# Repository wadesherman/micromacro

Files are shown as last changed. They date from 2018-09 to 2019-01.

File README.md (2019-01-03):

# micromacro
An 8 key macro keyboard

## Parts List
* 1x Sparkfun Pro Micro 5v
* 1x Breakaway Headers
* 8x Cherry Key Switches
* 8x Diodes
* 8x Keycaps
* 1x Case

Sparkfun Wishlist: <http://sfe.io/w149906](http://sfe.io/w149906>

## Assembly
1. Collect all your parts
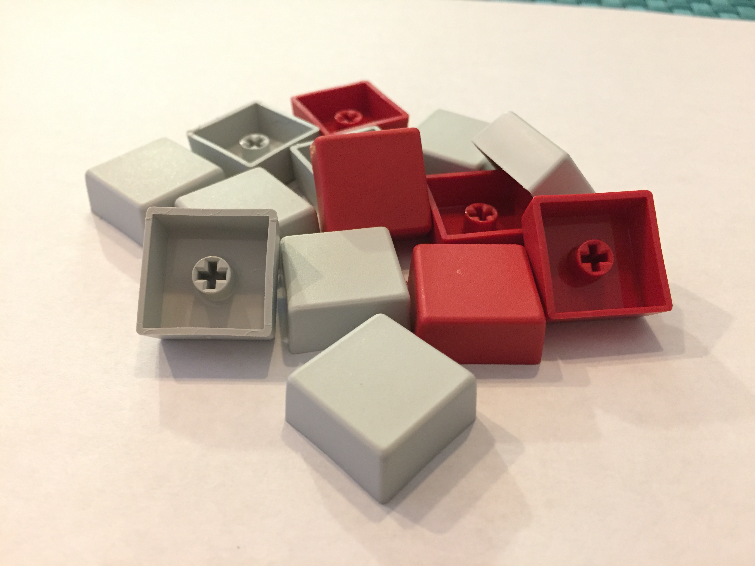
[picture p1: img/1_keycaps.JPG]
  
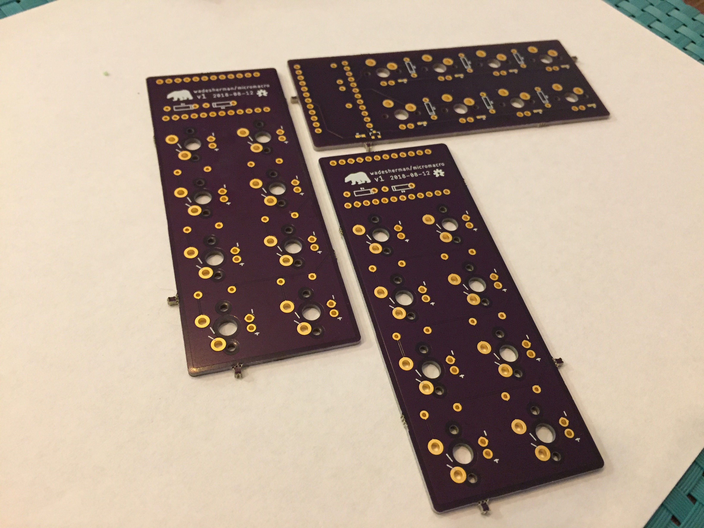
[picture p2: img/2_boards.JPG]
  
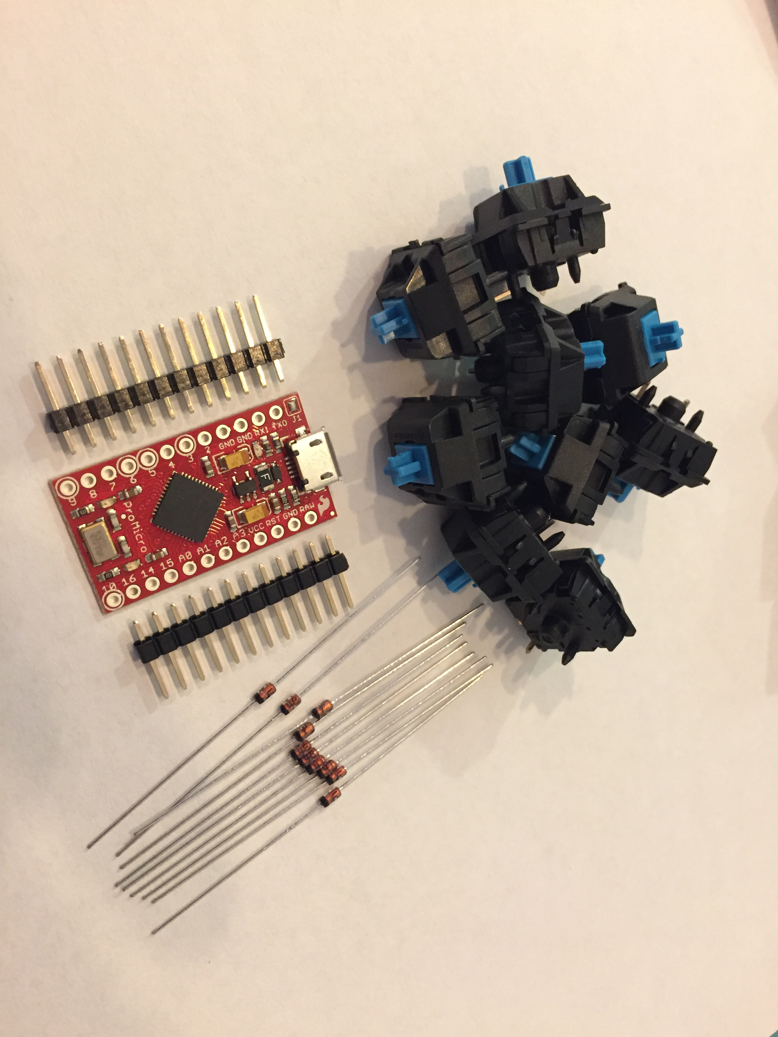
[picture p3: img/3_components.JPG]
  
2. Bend all the diodes - its easier and neater to bend them before
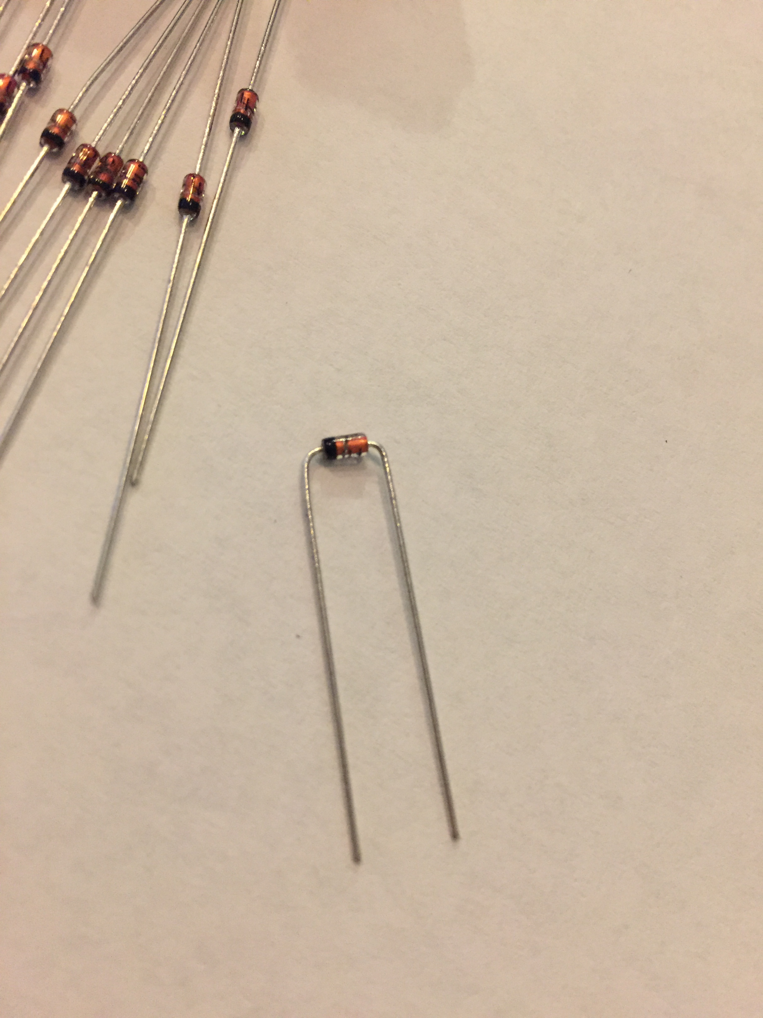
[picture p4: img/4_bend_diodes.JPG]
  
3. Populate the board with all the diodes and then solder them in place - bending the legs out a little will hold the diodes in place until you have a chance to solder them.
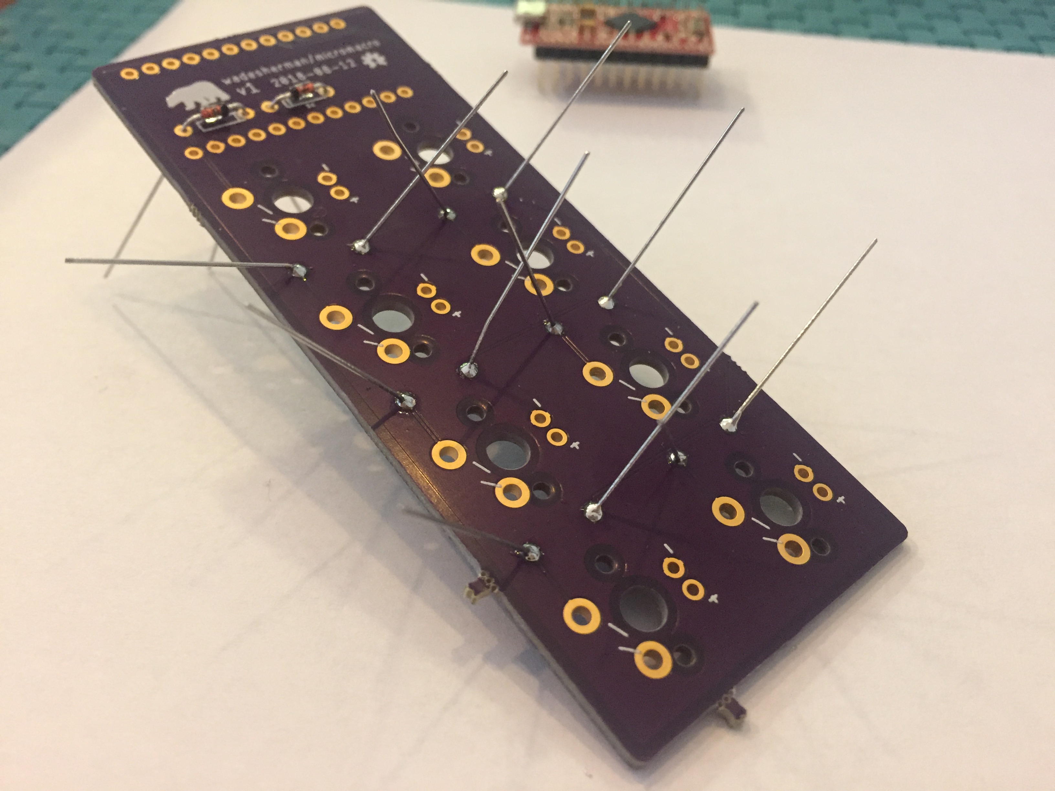
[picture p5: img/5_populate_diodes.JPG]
  
4. Solder the headers to the Pro Micro - it is easiest to just solder one or two pins to hold things together loosely.
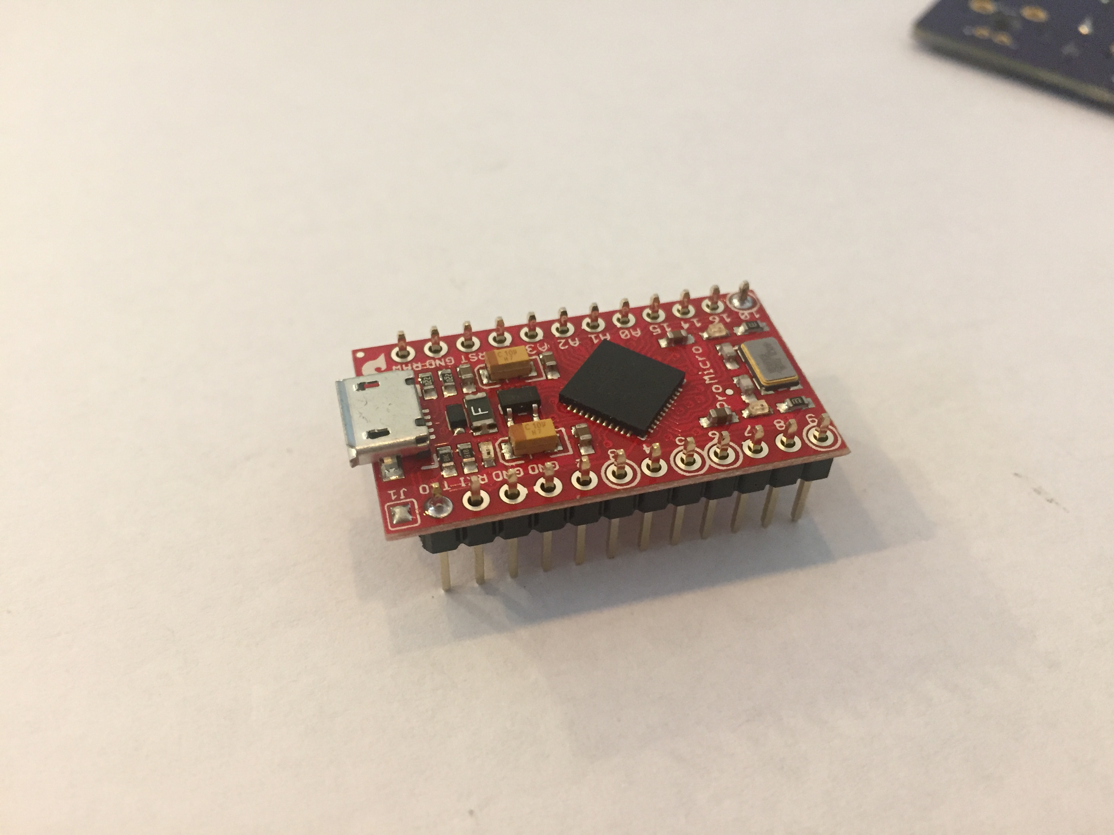
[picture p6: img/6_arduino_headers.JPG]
  
5. Solder the Pro Micro to the PCB - again, one or two pins
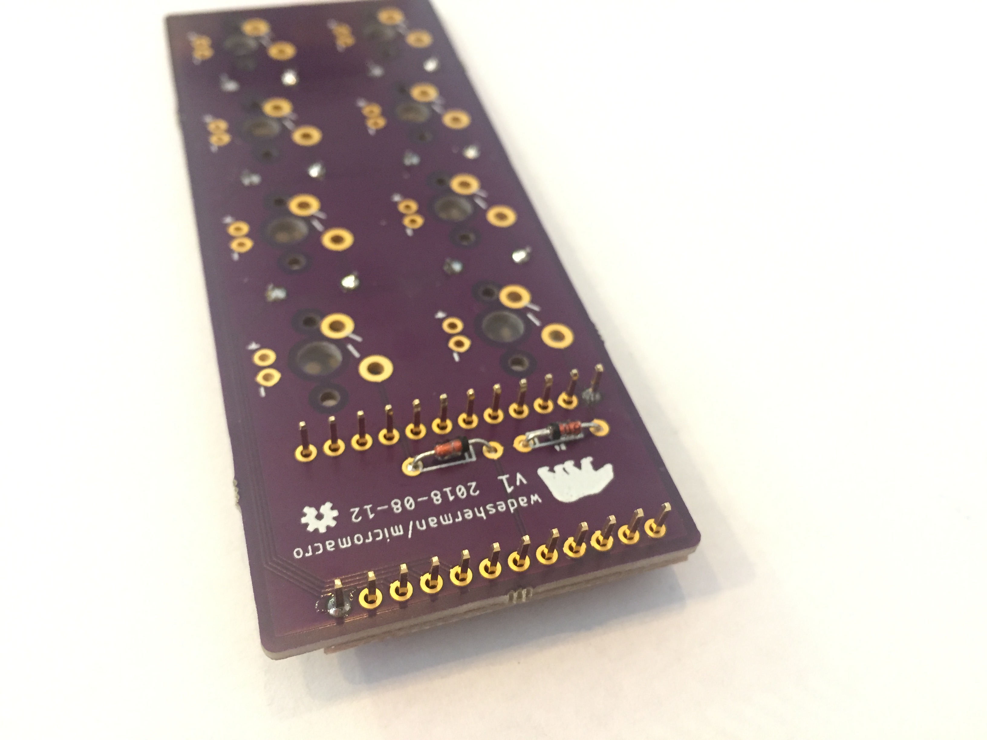
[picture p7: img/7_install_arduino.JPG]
  
6. Install Pro Micro to PCH and finish soldering all the rest of the pins
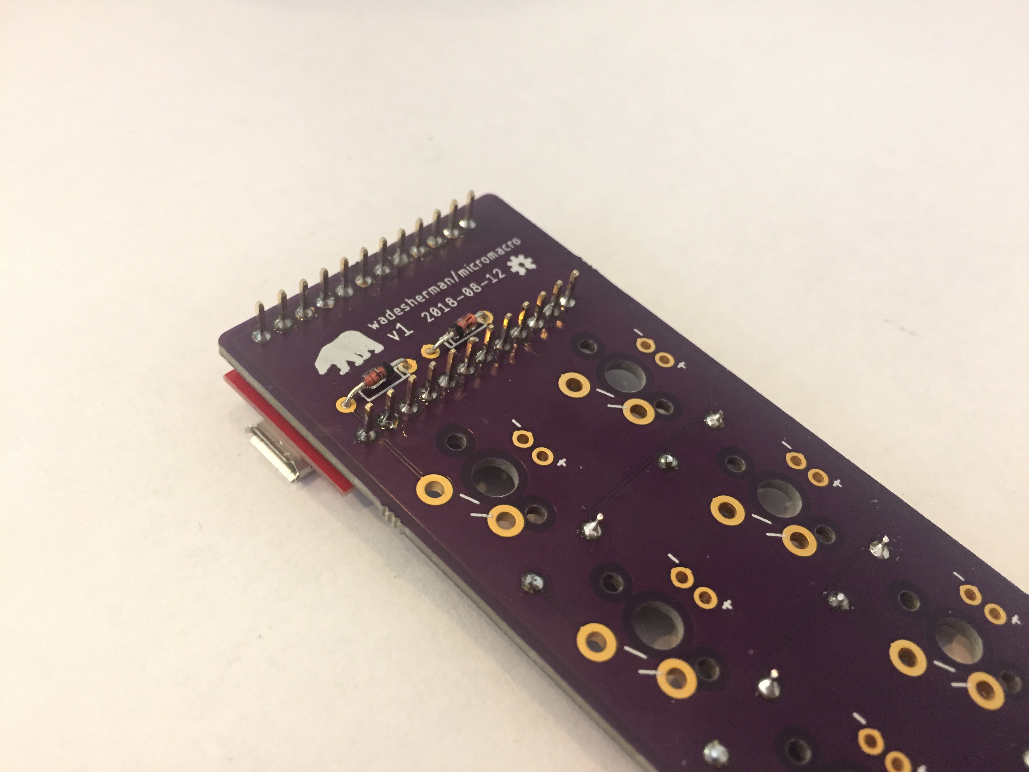
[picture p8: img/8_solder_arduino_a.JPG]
  
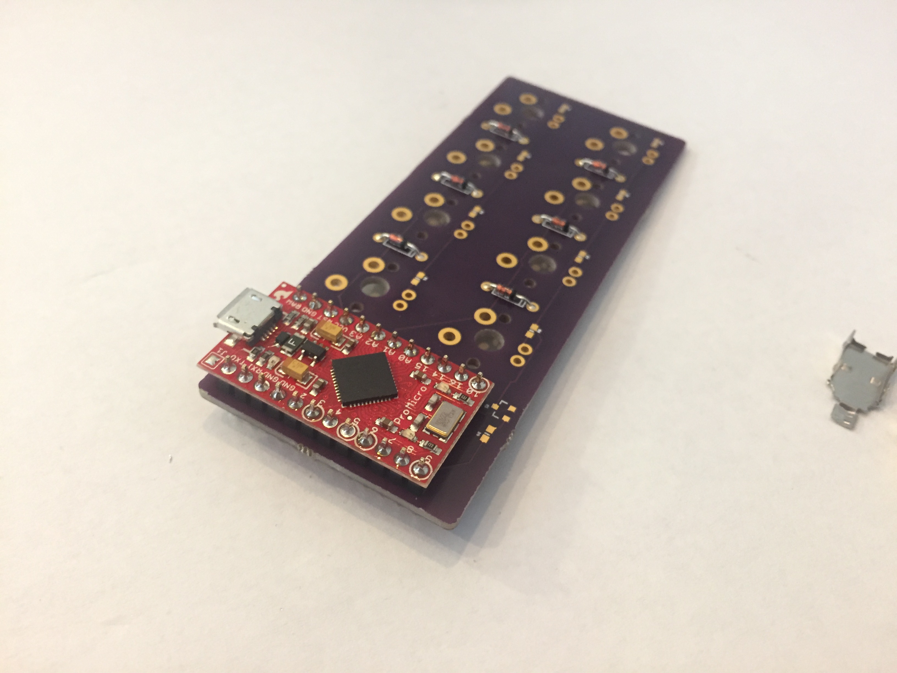
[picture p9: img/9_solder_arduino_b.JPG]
  
7. (optional) If using a plate, install the key switches to the plate
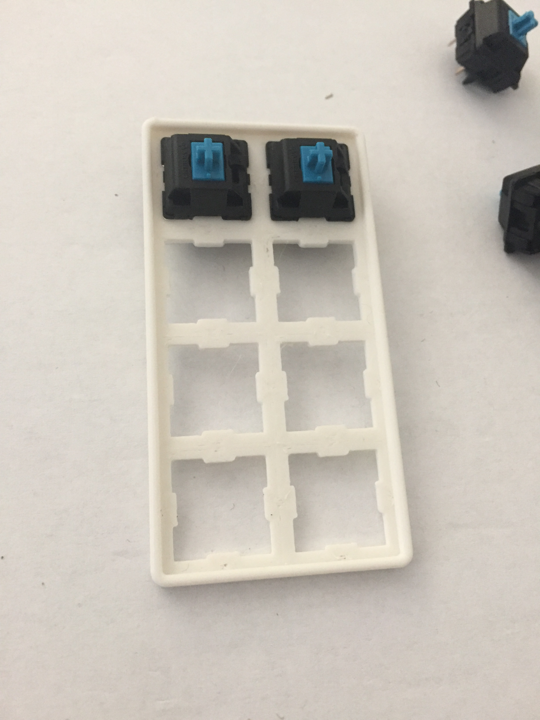
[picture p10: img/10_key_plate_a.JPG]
  
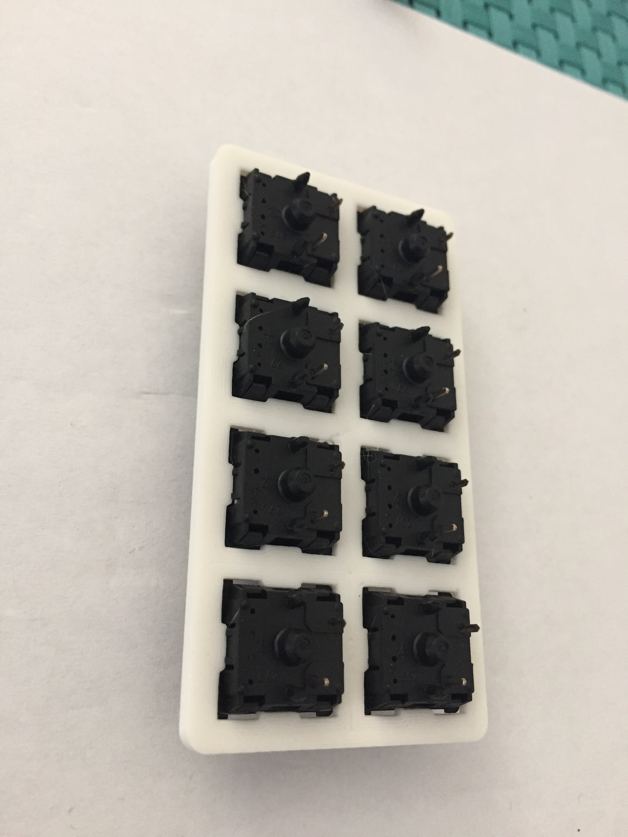
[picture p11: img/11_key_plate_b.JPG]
  
8. Install the switches to the PCB and solder.
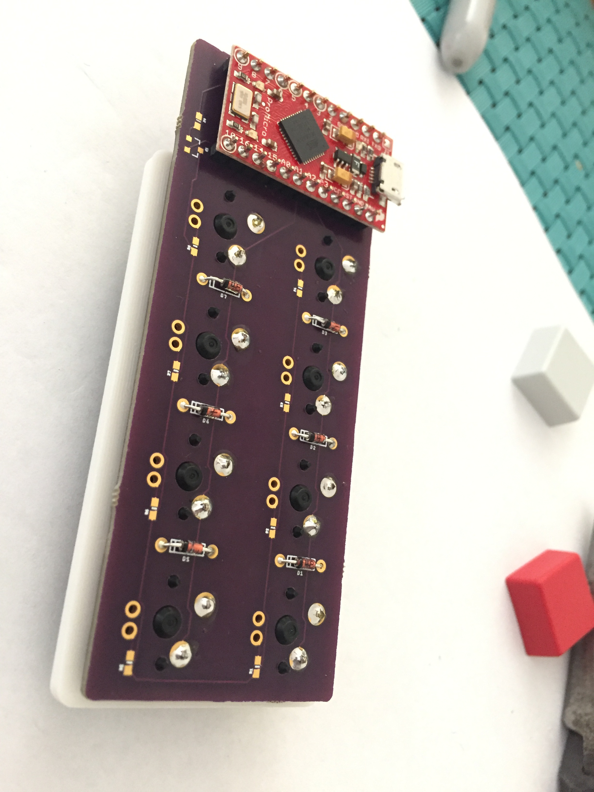
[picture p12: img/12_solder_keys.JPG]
  
9. Install keycaps.
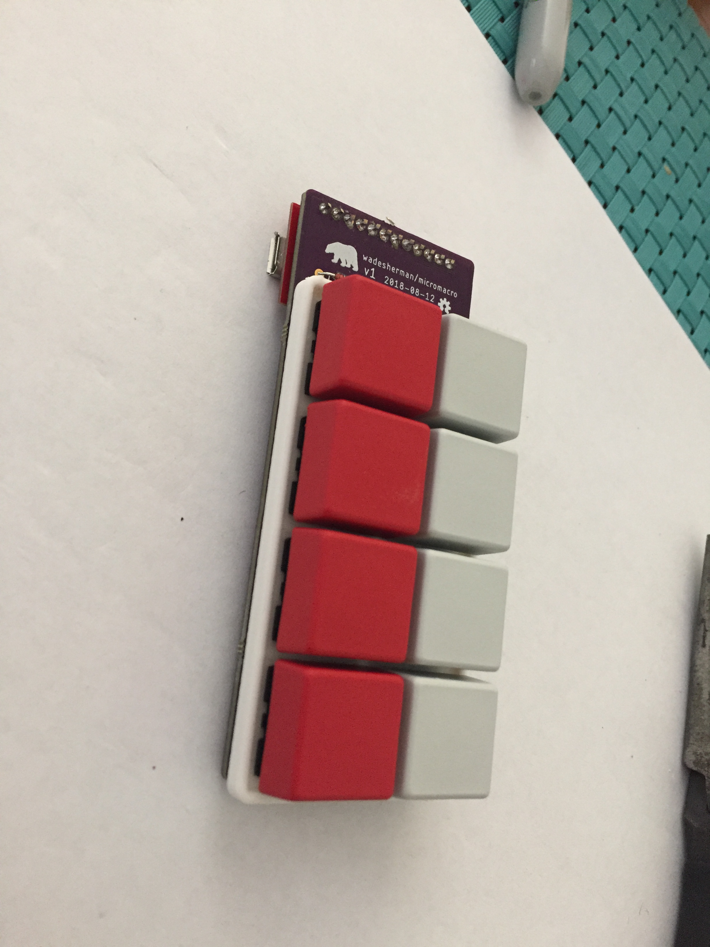
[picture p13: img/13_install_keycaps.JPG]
  
10. Install contraption into case. (STL file in /case)
11. Flash firmware to ProMicro. (Arduino sketch in /firmware)

[img_1]: https://github.com/wadesherman/micromacro/blob/master/img/1_keycaps.JPG "Keycaps"
[img_2]: https://github.com/wadesherman/micromacro/blob/master/img/2_boards.JPG "PCB"
[img_3]: https://github.com/wadesherman/micromacro/blob/master/img/3_components.JPG "Components"
[img_4]: https://github.com/wadesherman/micromacro/blob/master/img/4_bend_diodes.JPG "Bend Diodes"
[img_5]: https://github.com/wadesherman/micromacro/blob/master/img/5_populate_diodes.JPG "Populate Diodes"
[img_6]: https://github.com/wadesherman/micromacro/blob/master/img/6_arduino_headers.JPG "Pro Micro Headers"
[img_7]: https://github.com/wadesherman/micromacro/blob/master/img/7_install_arduino.JPG "Pro Micro Headers"
[img_8]: https://github.com/wadesherman/micromacro/blob/master/img/8_solder_arduino_a.JPG "Solder"
[img_9]: https://github.com/wadesherman/micromacro/blob/master/img/9_solder_arduino_b.JPG "Solder"
[img_10]: https://github.com/wadesherman/micromacro/blob/master/img/10_key_plate_a.JPG "Key Plate"
[img_11]: https://github.com/wadesherman/micromacro/blob/master/img/11_key_plate_b.JPG "Key Plate"
[img_12]: https://github.com/wadesherman/micromacro/blob/master/img/12_solder_keys.JPG "Solder Keys"
[img_13]: https://github.com/wadesherman/micromacro/blob/master/img/13_install_keycaps.JPG "Install Keycaps"

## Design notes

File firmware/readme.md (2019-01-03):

# Firmware

## Ardiuno Sketch
This .ino file can easily be installed to the Pro Micro using the Arduino IDE. 

Install [SparkFun's board files]( https://github.com/sparkfun/Arduino_Boards) so the IDE will recognize the Pro Micro.

**Be extra careful to select the correct version of the Pro Micro before flashing the firmware to the board**

## QMK
[QMK](https://github.com/qmk/qmk_firmware) supports the Pro Micro, so it is theoretically possible to run QMK on this with a custom layout.

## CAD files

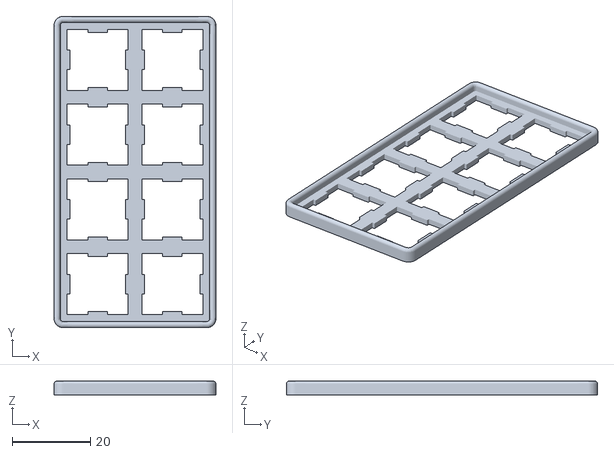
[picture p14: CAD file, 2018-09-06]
case/plate.stl
41.3 x 79.4 x 3.60

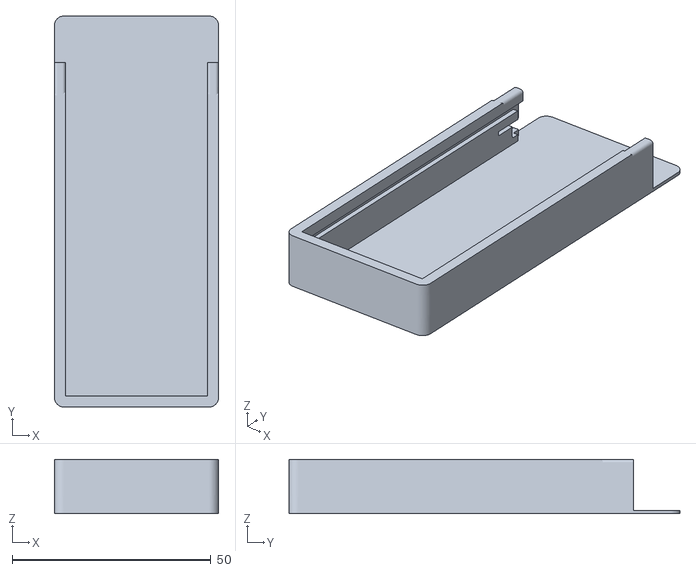
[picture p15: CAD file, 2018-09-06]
case/case1.stl
41.3 x 98.4 x 13.6

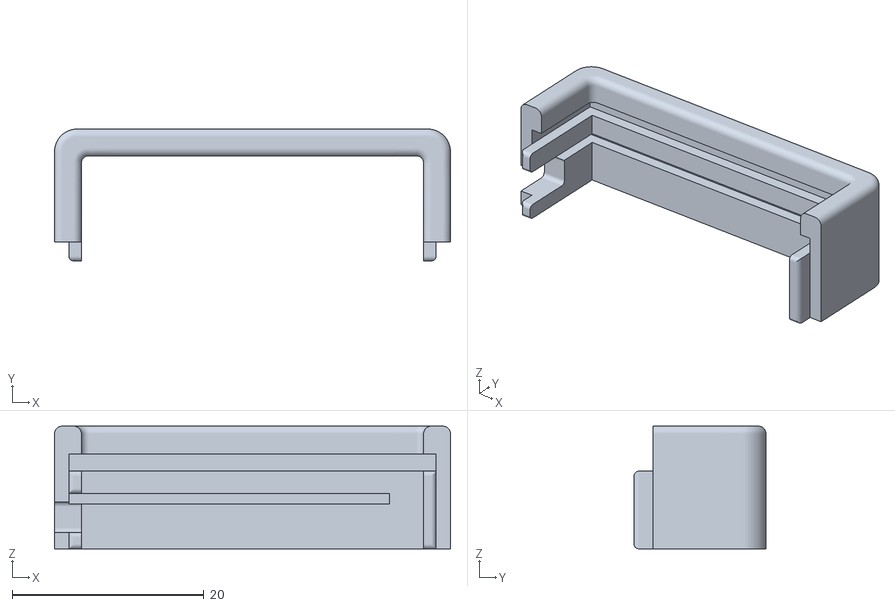
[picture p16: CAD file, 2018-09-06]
case/case2.stl
41.3 x 13.8 x 12.8

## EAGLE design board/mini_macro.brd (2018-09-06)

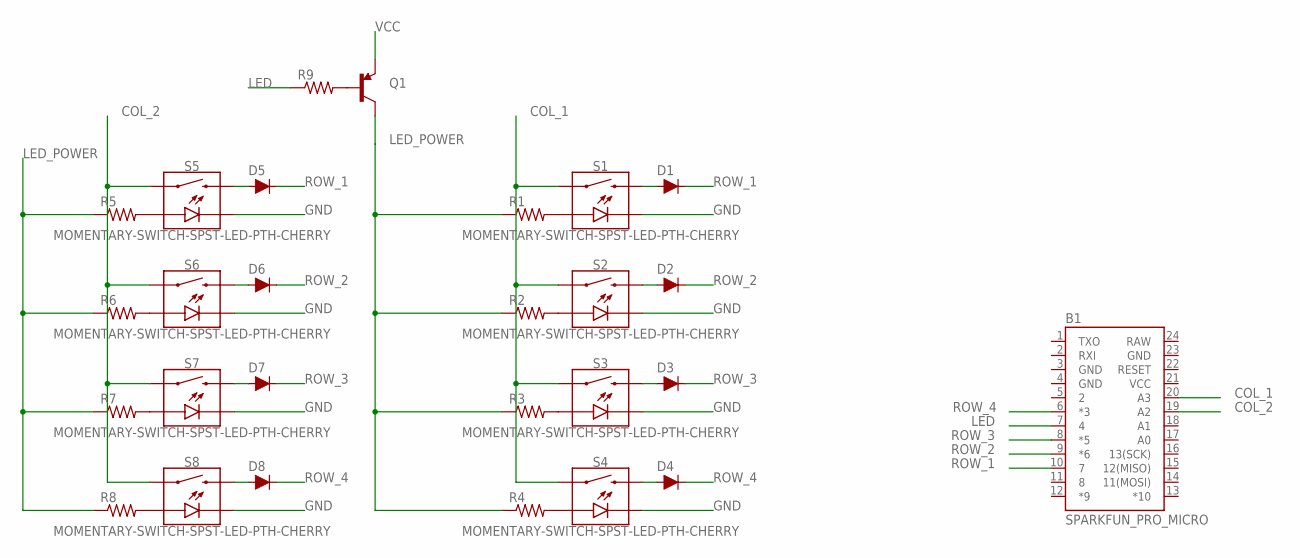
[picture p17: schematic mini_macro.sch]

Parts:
B1: SPARKFUN_PRO_MICRO
D1, D2, D3, D4, D5, D6, D7, D8: DIODE-1N4148
Q1: TRANSISTOR_PNPSMD; SOT23-3
R1, R2, R3, R4, R5, R6, R7, R8, R9: RESISTOR0603-RES; 0603-RES
S1, S2, S3, S4, S5, S6, S7, S8: MOMENTARY-SWITCH-SPST-LED-PTH-CHERRY; CHERRY-MX-LED

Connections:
COL_1: B1.20 (A3), S1.S1 (1), S2.S1 (1), S3.S1 (1), S4.S1 (1)
COL_2: B1.19 (A2), S5.S1 (1), S6.S1 (1), S7.S1 (1), S8.S1 (1)
GND: B1.3 (GND), B1.4 (GND), B1.23 (GND), S1.K (C), S2.K (C), S3.K (C), S4.K (C), S5.K (C), S6.K (C), S7.K (C), S8.K (C)
LED: B1.7 (4), R9.1
LED_POWER: Q1.3 (C), R1.1, R2.1, R3.1, R4.1, R5.1, R6.1, R7.1, R8.1
unnamed: D1.A, S1.S2 (2)
unnamed: D2.A, S2.S2 (2)
unnamed: D3.A, S3.S2 (2)
unnamed: D4.A, S4.S2 (2)
unnamed: D5.A, S5.S2 (2)
unnamed: D6.A, S6.S2 (2)
unnamed: D7.A, S7.S2 (2)
unnamed: D8.A, S8.S2 (2)
unnamed: R1.2, S1.A
unnamed: R2.2, S2.A
unnamed: R3.2, S3.A
unnamed: R4.2, S4.A
unnamed: R5.2, S5.A
unnamed: R6.2, S6.A
unnamed: R7.2, S7.A
unnamed: R8.2, S8.A
unnamed: Q1.1 (B), R9.2
RAW: B1.24 (RAW)
ROW_1: B1.10 (7), D1.C, D5.C
ROW_2: B1.9 (*6), D2.C, D6.C
ROW_3: B1.8 (*5), D3.C, D7.C
ROW_4: B1.6 (*3), D4.C, D8.C
VCC: B1.21 (VCC), Q1.2 (E)

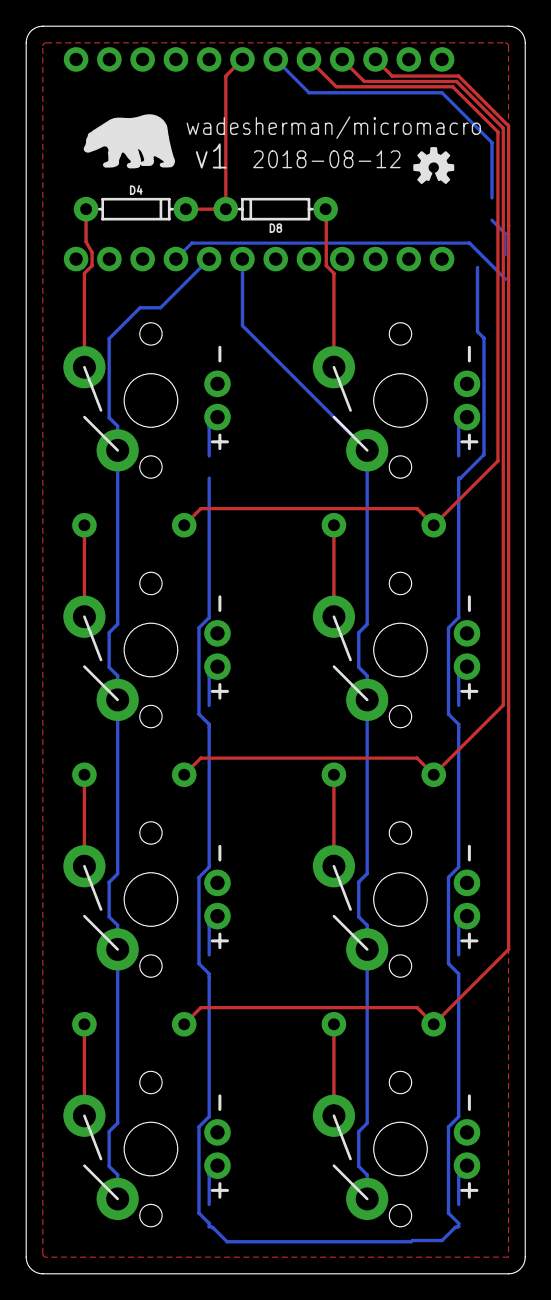
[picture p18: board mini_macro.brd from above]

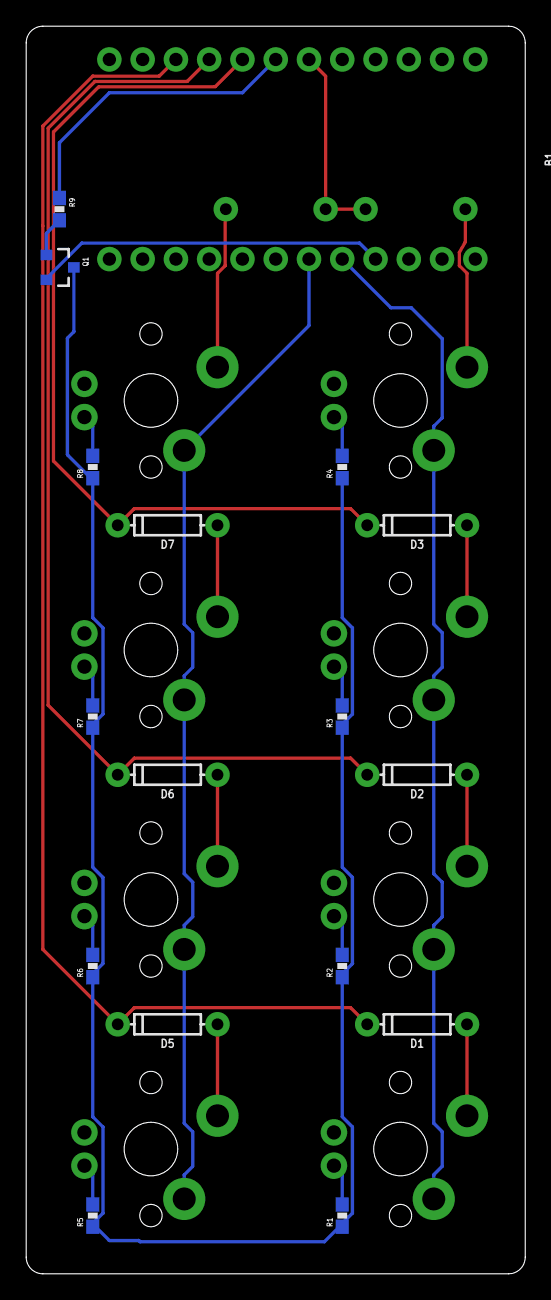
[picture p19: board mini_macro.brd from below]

Board: 2 copper layers, 38.1 x 95.2 mm, 29 parts (17 on the bottom side), 27 nets.

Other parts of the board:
U$1: OSHW-LOGO-S
U$2: BEAR

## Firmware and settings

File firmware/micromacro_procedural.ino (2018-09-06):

#include <Keyboard.h>

#define colCount 2
#define rowCount 4
#define debounceDelay 50

const int cols[colCount] = {21, 20};
const int rows[rowCount] = {7, 6, 5, 3};
const char* keys[colCount][rowCount] = {
  {"Key 1","Key 2","Key 3","Key 4"},
  {"Key 5","Key 6","Key 7","Key 8"}
};

bool keyStateLast[colCount][rowCount];
bool keyState[colCount][rowCount];
int keyDebounce[colCount][rowCount];

void setup() {
  
  //Rows are outputs, default to HIGH 
  for (int i = 0; i < rowCount; i++) {
    pinMode(rows[i], OUTPUT);
    digitalWrite(rows[i], HIGH);
  }
  
  //Cols are inputs, pulled high internally
  for (int i = 0; i < colCount; i++) {
    pinMode(cols[i], INPUT_PULLUP);
  }

  //initialize state and debounce arrays
  for (int r = 0; r < rowCount; r++) {
    for (int c = 0; c < colCount; c++) {
      keyStateLast[c][r] = false;
      keyState[c][r] = false;
      keyDebounce[c][r] = 0;
    }
  }
}


void loop() {
  // switch each row LOW
  for (int r = 0; r < rowCount; r++) {
    digitalWrite(rows[r], LOW);
    
    //and see if any cols go low.
    for (int c = 0; c < colCount; c++) {
        bool keyPress = !digitalRead(cols[c]);

        // if the keypress is different than the stored 
        // reading, start a debounce timer
        if (keyPress != keyStateLast[c][r]) {
          keyDebounce[c][r] = millis();
        }

        // if enough time has elapsed, read the button again
        if ((millis() - keyDebounce[c][r]) > debounceDelay) {

          // if the current state of the button matches the previous state
          // it is considered a legitimate press
          if (keyPress == keyStateLast[c][r]) {

            // if the current pin state is different than the stored state
            // store the new state
            if (keyPress != keyState[c][r]) {
              keyState[c][r] = keyPress;

              // if the state is going from high to low, send the message
              if (keyPress == true) {
                Keyboard.print(keys[c][r]);
              }
            }
          }
        }
        keyStateLast[c][r] = keyPress;
      }
    //then set the row back to HIGH.
    digitalWrite(rows[r], HIGH);
  }
    
}

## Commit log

2018-09-06 initial commit with firmware, board files and case files
    [case1.stl, case2.stl, mini_macro.brd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]
2019-01-03 add assembly images

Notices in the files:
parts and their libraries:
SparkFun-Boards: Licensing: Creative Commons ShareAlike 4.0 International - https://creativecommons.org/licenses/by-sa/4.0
